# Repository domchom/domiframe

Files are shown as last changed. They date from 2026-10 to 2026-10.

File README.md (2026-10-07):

# DomiFrame

Battery-powered color e-paper photo frames. Friends send pictures from a link on their phone; the frame picks them up on its next check-in.

- **Frame:** one of
  - Seeed XIAO ePaper Display Board **EE04** (XIAO ESP32-S3 Plus) + Seeed **7.3"** E Ink Spectra 6 panel (800×480), or
  - Seeed XIAO ePaper Display Board **EE02** (XIAO ESP32-S3 Plus) + Seeed **13.3"** E Ink Spectra 6 panel (1200×1600)
  - plus a 3.7 V LiPo
- **Server:** Netlify (static site + Functions + Blobs) at `domiframe.art`
- **Upload page:** dithers the photo to the panel's 6 inks in the browser, then **encrypts it there** with the frame's code, so the server only stores ciphertext

```
Friend's phone ──POST image──▶ domiframe.art ──▶ Netlify Blobs (picture queue per frame)
                                                      │
Frame (wakes on schedule or KEY1) ──GET + ETag────────┘
   304 unchanged → sleep     200 new picture → redraw (~20 s) → sleep
   Every reply says how long to sleep (X-Sleep-Minutes)
```

Each frame keeps up to 200 pictures, optionally sorted into folders; the frame cycles through one folder or all of them, in order or shuffled. New ones go up at the next check-in; any picture can be put up next on demand, or set to show only on a day (a birthday, every year); otherwise the frame rotates through them on a schedule (every hour, 3/6/12 hours, day, 3 days, week, or only when something new arrives). The server also decides when the frame wakes next: the check-in interval, quiet hours overnight, and fewer check-ins when the battery is low. When a check-in doesn't get through (no Wi-Fi, server down), the frame retries at its usual interval (`X-Retry-Minutes`), waiting twice as long after each failure in a row, up to 12 hours. A frame on USB power (firmware 0.9.8 tells the server with `X-Power: usb`) can **stay awake when plugged in**: with that setting on, it doesn't sleep, keeps Wi-Fi up and checks in every 5 minutes (`X-Awake-Seconds`), so new pictures go up within 5 minutes; quiet hours still put it to sleep, and unplugged it sleeps as usual. It only knows it's plugged in when there's no battery reading, i.e. no battery connected. When the battery is all but empty, the frame stops checking in and leaves its picture up (e-paper needs no power to keep it); it starts again once it's charged. Removed pictures stay in Recently removed for 30 days, so they can be put back. A frame that has never had a picture gets three paintings in a **Default** folder the first time its page is opened with its code (Hokusai's *Under the Wave off Kanagawa*, Van Gogh's *The Bedroom* and Seurat's *A Sunday on La Grande Jatte*, public domain from the Art Institute of Chicago, in `web/defaults/`), so a new or newly gifted frame isn't blank. The server can't add them itself (only someone with the code can seal pictures), so the first browser to ask claims them (`POST /api/frames/:id/defaults`); it happens once per frame code, and never to a frame that has had pictures. All of this is set per frame on the upload or admin page, with no reflashing.

## Several frames, and alerts

- **Also send to:** anyone with more than one frame opened on their device can send the same photos to several at once, from the upload page or the iPhone app. Each frame gets its own copy, made for its screen and orientation with the same crop, look and text, and sealed with its own code.
- **Alerts (iPhone app):** the app can tell you when a frame is late or its battery is low. The app registers its push token per frame (`/api/frames/:id/alerts`); every half hour `netlify/functions/send-alerts.mjs` checks those frames (`netlify/lib/alerts.mjs`) and sends through APNs (`netlify/lib/push.mjs`). Each problem is told once until it's over, and only between 8:00 and 21:00 where the frame hangs. A new frame code stops all of a frame's alerts. Locally, `POST /__dev/alerts` runs the check now and prints alerts if no APNs key is set.

## Repo layout

| Path | What it is |
|---|---|
| `web/` | Static site: home page (about + My frame), friend upload page, dithering (`dither.js`), encryption (`seal.js`), virtual frame (`sim.html`) |
| `netlify/functions/` | API endpoints |
| `netlify/edge-functions/invite-preview.js` | Invite links (`/f/<id>`) as a rich link in Messages etc.: the frame's ID in the preview tags, and the invite card `web/og-invite.png` (the home page's photo, in a frame). The code, after the `#`, never reaches the server |
| `netlify/lib/common.mjs` | Shared helpers (stores, key hashing, picture queue storage) |
| `netlify/lib/schedule.mjs` | Which picture to show and when the frame wakes (pure functions) |
| `web/admin.html` | Admin page: create frames, see battery and check-ins, replace keys |
| `firmware/` | PlatformIO project for the EE04 |
| `test/` | `npm test`: dithering, scheduling, full API flow against a local Blobs server |
| `scripts/` | `npm run local`: local server + virtual frame; `make-icons.py` redraws the favicons and link-preview images |
| `.github/workflows/ci.yml` | Runs the tests and compiles the firmware on every push |

## API

| Route | Auth | Purpose |
|---|---|---|
| `POST /api/admin/frames` `{id, name, panel?}` | admin | Create a frame; returns `deviceKey` (shown once). No frame code: the frame makes that |
| `GET /api/admin/frames` | admin | List frames: check-ins, battery, settings, picture counts (nothing uploaded) |
| `DELETE /api/admin/frames/:id` | admin | Delete a frame and its pictures |
| `POST /api/admin/frames/:id/keys` `{key: "device"}` | admin | Replace the device key (old one stops working), shown once |
| `PUT /api/admin/frames/:id/settings` | admin | Settings other than the folder, e.g. `orientation` |
| `POST /api/frames/:id/code` `{hash}` | `X-Device-Key` | The frame registers a new code (SHA-256 of the token derived from it); puts the frame's pictures aside for 30 days, or brings them back if it's the code from before |
| `GET /api/frames/:id/image` | `X-Device-Key` | Frame download, sealed (`ETag` / `304`, `204` if empty), always with `X-Sleep-Minutes`, `X-Retry-Minutes`, `X-Orientation`, `X-Flip` and `X-Local-Time`, and `X-Fw-Update` etc. when newer firmware is out. `X-Next: 1` moves to the next picture now (KEY2); `X-Status: 1` only checks in (`204` with `X-Frame-Name` and `X-Pictures`) |
| `POST /api/frames/:id/image` | upload key | Add a picture: packed image, preview PNG, and optionally `thumb` JPEG, original JPEG, `edits`, `from`, `album`, `queue` |
| `GET /api/frames/:id/info` | upload key | Name, check-ins, battery, settings, picture queue |
| `GET /api/frames/:id/preview` | upload key | PNG of the picture on the frame now |
| `PUT /api/frames/:id/settings` | upload key | `rotateHours`, `checkMinutes`, `album`, `order`, `quiet`, `quietStart`, `quietEnd`, `tz`, `orientation`, `flip` (hung upside down) |
| `GET /api/frames/:id/pictures/:pic` | upload key | One picture's PNG preview |
| `GET /api/frames/:id/pictures/:pic/thumb` | upload key | Small JPEG for the picture grid (the PNG preview for older pictures) |
| `GET /api/frames/:id/pictures/:pic/original` | upload key | The photo as uploaded (JPEG), for editing again |
| `PUT /api/frames/:id/pictures/:pic` | upload key | Replace with an edited version (keeps place and folder) |
| `POST /api/frames/:id/pictures/:pic/show` | upload key | Put it up at the next check-in |
| `DELETE /api/frames/:id/pictures/:pic` | upload key | Remove one picture (to the trash) |
| `DELETE /api/frames/:id/pictures` `{ids}\|{album}\|{all: true}` | upload key | Remove several (to the trash); returns their `ids` |
| `PATCH /api/frames/:id/pictures` `{ids, album}` | upload key | Move to a folder (`album: null` = none) |
| `PATCH /api/frames/:id/pictures` `{ids, day}` | upload key | Show only on a day: `"MM-DD"` every year, `"YYYY-MM-DD"` once, `null` = any day |
| `POST /api/frames/:id/restore` `{ids}` | upload key | Put pictures back from the trash |
| `DELETE /api/frames/:id/trash` `{ids}\|{all: true}` | upload key | Delete pictures in the trash for good (otherwise after 30 days) |
| `POST /api/frames/:id/defaults` | upload key | `{claimed}`: true for the one browser that should add the default pictures (a frame that has never had any, once per code) |
| `POST /api/frames/:id/albums` `{name}` | upload key | New folder |
| `PUT`/`DELETE /api/frames/:id/alerts` `{apns, sandbox?, tz?}` | upload key | Start/stop alerts to the iPhone app when the frame is late or its battery is low |
| `PATCH`/`DELETE /api/frames/:id/albums/:album` | upload key | Rename / delete (`?pictures=keep\|delete`) |

"admin" means `Authorization: Bearer <ADMIN_TOKEN>`; "upload key" means `Authorization: Bearer <token derived from the frame code>` (below). The admin token does **not** open any frame's pictures.

Image format: 4 bits per pixel, two pixels per byte (high nibble = left), rows in the panel's own layout: 7.3" = 800×480 (192,000 bytes), 13.3" = 1200×1600 (960,000 bytes). Pictures made for the frame's orientation are turned 90° clockwise when it hangs the other way from the panel's rows (`toPanelOrder` in `web/dither.js`). A frame hung upside down (`flip`) gets the same pictures and turns everything it draws 180° itself (firmware 0.9.7 and later); the picture's ETag changes with `flip`, so the frame draws it again the other way up. Each frame has a `panel` setting (`"7.3"` or `"13.3"`); it is chosen when the frame is created on the admin page; the firmware reports its own on every check-in (`X-Panel`), while the virtual frame only does when its size is changed and otherwise takes the size from the reply (`X-Panel`, like `X-Orientation`). Pictures made for another screen size are never sent.
Palette indices: `0 black, 1 white, 2 yellow, 3 red, 4 blue, 5 green` (shared by `web/dither.js` and `firmware/src/main.cpp`).

Picture files never change (editing a picture gives it a new id), so they're served with `Cache-Control: immutable` and browsers only download each one once. Changes to a frame's picture queue are conditional writes (`onlyIfMatch`), retried on conflict, so a frame checking in during an upload can't lose a picture.

## Privacy: pictures are end-to-end encrypted

Nobody who runs the server (including you, the developer) can see what people send. Each frame makes its own **frame code** like `K7PX-92QD-M4TR-8WZN` (16 characters of Crockford base32, 80 random bits from the ESP32's hardware RNG) and shows it on its screen. The code never goes to the server:

- From the code and frame ID, `web/seal.js` derives two unrelated keys with HKDF-SHA256: an **access token** (sent as the bearer token; the server stores only its SHA-256) and an **AES-256-GCM key**.
- The upload page seals everything before it leaves the browser: the frame picture, preview, thumbnail, original photo, edit settings, sender name and folder names. The server stores and serves ciphertext (`application/octet-stream`).
- The frame derives the same key (`frameKey` in `firmware/src/main.cpp`, mbedtls) and opens the picture before drawing it. The virtual frame does the same with WebCrypto.
- The admin page creates frames and device keys, and shows battery, check-ins and picture counts. It never gets a frame code and can't open, replace or delete anyone's pictures.

The frame's code screen also has a QR code of `https://domiframe.art/f/<id>#k=<code>` (drawn with ESP-IDF's built-in QR encoder), so a phone can open the frame straight away. Codes can also be typed: the home page's **My frame** tab takes a frame ID and code (or a pasted link) and remembers frames opened on that device. Codes are forgiving about case, spaces, dashes and O/I/L (`web/code.js`). In links the code travels in the `#fragment`, which browsers never send, and the upload page removes it from the address bar once saved.

**New code:** on the frame's Wi-Fi setup page (hold KEY3 and press reset), open *Frame details* and tick *Make a new frame code*. The old code stops working. The frame's pictures and folders were sealed with the old code, so they're put away: still sealed, and back only if the frame goes back to that code (type it into the setup page's *Frame code* field) within 30 days, after which they're deleted. The same field gets a wiped frame back to its code and pictures. Changing the frame ID also makes a new code. If you set a frame up before gifting it, the new owner can do this so only they have the code, at the cost of the pictures sent before (the new code starts with the default paintings). **Show the code again:** hold KEY1 while pressing reset.

**What this protects against:** anyone reading the stored data, the database, logs, or the admin page. **What it can't:** the server also serves the web pages, so whoever controls the site could in principle ship changed JavaScript that reads codes as they're typed. The CSP (below) stops pages loading code from anywhere else, but the site's own code has to be trusted. What the server does see: frame names, when pictures were uploaded, how many there are, and settings.

## Other protections

- **Security headers** on every page and API reply (`netlify.toml`, also sent by `npm run local`): a strict Content-Security-Policy (only this site's own scripts, no inline code, requests only to this site, no framing), HSTS, `X-Frame-Options: DENY`, `Cross-Origin-Opener-Policy`, `Cross-Origin-Resource-Policy`, `Permissions-Policy`, `nosniff`, `no-referrer`. No third-party scripts: the virtual frame's QR library is a copy in `web/vendor/`.
- **Keys:** device keys and access tokens are stored only as SHA-256 hashes and compared in constant time. The admin token is kept in the browser tab's `sessionStorage` (gone when the tab closes), and it works only on `/api/admin/*`.
- **Wi-Fi setup:** the `DomiFrame-Setup` Wi-Fi has a new random password each time, shown on the frame's screen (and in its join QR code), so nobody nearby can join it without seeing the frame. The setup page (`firmware/src/portal.cpp`, served by the frame itself) never shows the saved device key, frame code or Wi-Fi password back, and has no firmware upload: updates only come signed, over Wi-Fi.
- **Frame to server:** TLS is checked against Mozilla's root CAs (below). Sealed pictures that don't open with the frame's key (tampered with, or sealed with an old code) are never drawn.

## Deploy (Netlify)

1. New site from this GitHub repo. Build settings come from `netlify.toml` (publish `web`, functions `netlify/functions`). Pushes that only change firmware, tests or docs skip the deploy (`ignore` in `netlify.toml`), which saves credits on the Free plan.
2. **Site configuration → Environment variables:** add `ADMIN_TOKEN` (a long random string, e.g. `openssl rand -base64 32`). Optionally `PUBLIC_URL=https://domiframe.art`.
   For the iPhone app's alerts, also add an APNs key (Apple Developer → Certificates, IDs & Profiles → Keys, with Apple Push Notifications service): `APNS_KEY` (the `.p8` file's contents), `APNS_KEY_ID`, `APNS_TEAM_ID`, and `APNS_TOPIC` if the app's bundle ID isn't `art.domiframe.app`. Without them, nothing is sent.
3. **Domain management:** add `domiframe.art` and follow Netlify's DNS instructions at your registrar.

## Add a frame

Open `https://domiframe.art/admin.html`, sign in with `ADMIN_TOKEN`, and use **Add a frame**. It shows the device key once, with a link to try it as a **virtual frame** right away. Once the frame (real or virtual) is set up, it makes its frame code and shows it on its screen: give that code and the frame ID to the owner. **New device key** replaces a leaked key.

Or with curl:

```bash
curl -X POST https://domiframe.art/api/admin/frames \
  -H "Authorization: Bearer $ADMIN_TOKEN" -H "Content-Type: application/json" \
  -d '{"id":"emma","name":"Emma'\''s frame"}'
```

Save the response and enter `id` + `deviceKey` on the frame (below). The frame then shows its code.

## Flash and set up a frame

1. 7.3": set the EE04 jumper to **50-pin** for the Seeed 7.3" panel. 13.3": connect the panel to the EE02's 60-pin connector.
2. Flash the build for your screen (PlatformIO), with the board on USB-C:
   - 7.3" on EE04: `cd firmware && pio run -e ee04 -t upload`
   - 13.3" on EE02: `cd firmware && pio run -e ee02-13in3 -t upload`
3. On first boot the screen says **Set up Wi-Fi**, with a QR code. Scan it with a phone's camera to join the frame's own `DomiFrame-Setup` Wi-Fi (or join it by hand with the password on the screen), and a setup page opens: pick the home network, type its password, choose how the frame hangs, fill in **Frame ID** and **Device key**, and press **Connect**. The page says whether it worked; a wrong password keeps it open to try again. The orientation can also be changed later on the upload or admin page.
4. The frame connects, makes its **frame code** and shows it with the frame ID and a **QR code**. Scan the QR code to open the frame's page with the code filled in, or enter the ID and code under **My frame** on domiframe.art.
5. When the frame is switched on (or reset, or KEY1 is pressed) and can't reach its Wi-Fi, because it has moved or been given away, it opens setup by itself. Only the Wi-Fi is asked for: the frame's details are under *Frame details*, and its pictures stay. On a timer wake it just keeps its picture and tries again later. To open setup anyway (a new frame code, say), hold **KEY3** while pressing reset. Hold **KEY1** while pressing reset to show the code again (no Wi-Fi needed).
6. **KEY1** wakes the frame to check for a new picture immediately. **KEY2** wakes it and puts up the next picture (`X-Next: 1`; it then stays a whole turn). Hold **KEY2** while pressing reset for the status screen: battery, Wi-Fi and signal, whether the server answers (a check-in with `X-Status: 1`, which leaves the picture as it is) and the last check-in that got through, in the frame's time zone (`X-Local-Time`).

You can do step 3 yourself with your own Wi-Fi before gifting it, and open its page so it gets the default paintings (and send any pictures you'd like waiting). Switch it off before sending it: when your friend switches it on at home, it can't find your Wi-Fi, opens setup, and they only pick theirs. To keep their pictures private from you, they can open *Frame details* there and tick *Make a new frame code*, though the pictures sent before are put away with the old code. The support page has the same steps (`web/support.html#gift`).

## Firmware updates over Wi-Fi

Frames update themselves: when a newer release is out for their build, the check-in reply offers it (`X-Fw-Update`, `X-Fw-Url`, `X-Fw-Size`, `X-Fw-Sig`), and the frame downloads it into the spare app slot, checks it, and restarts into it. The picture stays on the screen, and the frame keeps its Wi-Fi, settings and frame code, so its pictures stay too. It only installs firmware **signed with your key** (ECDSA P-256, checked against the public key built into it), only a newer version of the same build, and only with enough battery (`MIN_UPDATE_MV`). The new firmware only counts as good once it has reached the server; until then the bootloader can roll it back, where it supports that. Three failed tries at one version and the frame waits for a newer one.

1. Once: `cd firmware && python3 tools/release.py keygen`. This makes the signing key at `~/.domiframe/firmware-signing-key.pem` (outside the repo: back it up, never commit it) and writes its public half into `include/fw_key.h`. Commit that file, and flash each frame **once over USB** so it has the key. Until `fw_key.h` holds a key, frames don't ask for updates.
2. Each release: raise `FW_VERSION` in `include/config.h`, then `python3 tools/release.py publish`. It builds both screens, signs them, puts them in `web/firmware/` and lists them in `netlify/lib/firmware-releases.mjs`.
3. Commit and push. Once Netlify deploys, each frame updates at its next check-in.

Lose the key and frames can't take updates over Wi-Fi any more: make a new one with `keygen`, and flash every frame over USB again.

## Local development

```bash
npm install
npm test        # dithering + API flow
npm run local   # whole system locally, with a virtual frame (no hardware, no Netlify account)
npx netlify dev # site + functions locally (needs netlify-cli)
```

### Testing without hardware

**Virtual frame** (`/sim.html`, also live at `https://domiframe.art/sim.html`): a browser stand-in for the frame that works against the real site too. Create a frame on the admin page and press **Open as a virtual frame** (or enter the frame ID and device key on the page). Like the firmware, it makes its own frame code, registers it, shows it on its screen, sends the device key, battery and `If-None-Match`, opens the sealed picture with its code, and decodes the packed 4bpp image with the same palette. **Open this frame's page** opens the upload page with the code. Press **KEY1** to check in, or turn on auto wake. The device key and code are kept in that browser's storage.

`npm run local` starts the site and API on `http://localhost:8888` with a local Blobs store in `.local/`. It creates a `demo` frame and prints a link to the virtual frame for it. Use the battery slider to test the upload page's battery display.

To start over, delete `.local/`. The admin page is at `/admin.html` with the token `local-admin`.

To test schedules, the virtual frame can follow the server's `X-Sleep-Minutes` in real time or sped up, or skip ahead an hour, day or week. The local server moves its clock to match (`/__dev/clock`, local only), so you can watch hourly or weekly rotation and quiet hours in seconds.

## Status / to verify on real hardware

- Firmware **compiles** (CI builds both screens on every push) but has **not run on hardware yet**. 7.3": pins come from Seeed's `Seeed_GFX` EE04 setup and the EE04 wiki; the display uses GxEPD2's `GxEPD2_730c_GDEP073E01` driver, which targets the same ED2208 controller as Seeed's 7.3" Spectra 6 panel. 13.3": uses Seeed's own `Seeed_GFX` (`BOARD_SCREEN_COMBO=510`, T133A01 driver), pinned to a known commit.
- EE02 buttons and battery pins aren't published; the 13.3" build assumes they match the EE04 (its display pins do). Check against the EE02 schematic.
- On a frame hung the other way from its panel's rows (a portrait 7.3", a landscape 13.3"), check that pictures and status messages are the right way up; if not, flip `rotateCW` in `web/dither.js` and the rotation in `showMessage()`.
- TLS: the frame checks the server's certificate against Mozilla's root CAs, embedded as `firmware/data/cert/x509_crt_bundle.bin` (`VERIFY_TLS` in `config.h`), so it keeps working whichever CA issues the certificate. Unlike a browser, the ESP32 only looks up the issuer of the *last* certificate the server sends, so after pointing domiframe.art at Netlify, check it: `python3 firmware/tools/make_ca_bundle.py --check domiframe.art` (CI also runs this weekly). If it names a missing root, add it to `firmware/tools/extra_roots.pem`, rebuild the bundle and reflash. Rebuild it every year or so anyway: `python3 firmware/tools/make_ca_bundle.py`.
- Wi-Fi: the frame remembers the access point and channel in RTC memory across deep sleep and reconnects without scanning, falling back to a normal connect if that fails within 5 s.
- How each frame hangs (landscape or portrait) is a frame setting. Pictures for a portrait frame are packed turned 90° clockwise onto the panel; if they come out upside down on a real portrait-hung frame, flip the rotation in `web/dither.js` (`rotatePortraitToPanel`).
- Palette RGB values in `web/dither.js` are approximations of the real inks; tune them after comparing the preview with the panel.
- Battery reading uses Seeed's `raw / 4096 × 7.16` formula; check against a multimeter.

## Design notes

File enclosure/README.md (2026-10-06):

# Frame case

A 3D-printable case for the 7.3" panel, the Seeed XIAO ePaper Display Board and a LiPo battery. The screen glass is 169 × 111 mm, with a 160 × 96 mm image area. The battery space fits an 80 × 55 × 9 mm pack, so there's room for the larger battery you plan to use later.

The size starts from hextheboy's [7.3 inch E-ink Paper Frame](https://makerworld.com/en/models/1710103-7-3-inch-e-ink-paper-frame) on MakerWorld (191.2 × 132.2 × 16 mm). This version is 196.2 × 132.2 × 17 mm:

- **1 mm deeper**, so there's 7.4 mm of free space above the board for the battery connector. The model refuses to render if that drops below `board_clearance` (6 mm) plus 0.5 mm.
- **5 mm wider**, so the bezel is 18.6 mm on all four sides. The screen's image area isn't centred on its glass, so the glass sits 4 mm low in the frame to centre the window. Set `equal_bezels = false` to go back to the reference width with a wider bottom bezel.

Everything fits inside that depth, so the back is a flat plate with no lid sticking out. The board sits against the top wall, with its buttons, slide switch and USB-C facing up. The top wall has an opening for the USB-C plug and a round hole over each button. A small printed cap goes through each hole and presses onto the switch's plunger. The slide switch has a slot, and its cap has a wider tab outside so it's easier to push.

| File | Print orientation |
| --- | --- |
| `stl/frame.stl` | front face down |
| `stl/back.stl` | outside face down |
| `stl/buttons.stl` | four button caps and the switch cap, outer face down |
| `stl/fit_test.stl` | fit test caps, see below |
| `stl/rail.stl` | landscape hanging rail and two spacers, back face down |
| `stl/stand.stl` | two stand feet, flat on their side |

The source is `domiframe_case.scad`. All the dimensions are parameters at the top of the file.

## Check these before printing

Most of these numbers came from a photo, so measure your parts first:

- **`edge_to_hole`** (now 2.5 mm): the distance from the button edge of the board to the centres of the nearest mounting holes. The standoffs set where the board sits, so if this number is wrong, the buttons won't line up with the slot.
- **`board_len` / `board_wid`** (now 80 × 41.2 mm): the outline of the board.
- **`usb_x`** (now −25): where the USB-C sits along the top wall. The buttons are placed from it: the first is `btn_first` (16.87 mm) away, then every `btn_pitch` (9.16 mm). If they all end up on the wrong end, flip the sign of `usb_x` and set `btn_dir = -1`.
- **`usb_above_pcb`** (3.0 mm): how far the centre of the USB-C port sits above the top of the PCB. The opening is centred on this height. It's 12.5 × 7 mm (`usb_hole_w`, `usb_hole_h`) so the plug's overmold can go partway into the wall. If your cable's overmold is bigger, make the opening bigger.
- **`usb_overhang`** (0): if the USB-C socket sticks out past the board edge by more than 0.3 mm, set this to how far. It cuts a groove up the inside of the wall so the socket can slide in when the back plate goes in.
- **`btn_from_back`** (8.15 mm, measured): how far the centre of each plunger sits from the back face of the frame. The holes and caps are centred on this height.
- **`sw_window`** (3.84 mm, measured): the opening in the switch body. The knob slides 3.84 − 1.55 = 2.29 mm in it. `sw_on_from_btn` (10.75 mm, measured) places it in the ON position, counted from the last button, and OFF is `sw_travel` back toward the buttons. The slot is also 1.5 mm taller than it needs to be (`sw_z_play`, 0.75 mm on each side), because the knob's distance from the back (`sw_from_back`, 8.15 mm) doesn't seem to be exactly the same each time.
- **`sw_post_len`** (1.5 mm): how far the knob sticks out of the switch body. The cap goes `sw_grip` (1 mm) onto it.
- **`btn_tip`** (0): where the tip of each plunger sits relative to the board edge. It's negative if the tip stops short of the edge. Each cap's sleeve reaches in to the plunger, so this sets how long the caps are.
- **`btn_post_len`** (1.5 mm): how far each plunger sticks out of the switch body. Each cap goes `btn_grip` (1 mm) onto the plunger and no further, because its socket is closed at the end. The model refuses to render unless `btn_travel` (0.3 mm) plus 0.1 mm is left between the cap and the switch body, so the cap doesn't hold the button down.
- **`aa_top`** (5 mm): the gap between the top edge of the glass and the top of the image area. The bottom border, on the FPC side, works out to 10 mm, and each side to 4.5 mm.

The quickest check is to print only a strip of the top wall and hold your board against it.

### Button caps

The plungers taper from 2.35 mm at the base to 2.3 mm at the tip. The socket in each cap is drawn at 2.3 mm (`btn_bore`). Small printed holes usually come out about 0.1 mm undersize, and that gives the press fit. Print `fit_test.stl` first. It has four button caps with sockets of 2.2, 2.3, 2.4 and 2.5 mm, marked with 1 to 4 dots on the outer face. Push each one onto a plunger, and set `btn_bore` to the socket size of the one that holds firmly without splitting.

The switch knob is a 1.55 mm square, and its cap's socket is drawn at that size (`sw_socket`). The fit test also has three switch caps with sockets of 1.45, 1.55 and 1.65 mm, marked with 1 to 3 dots. Set `sw_socket` the same way.

## Rendering

Export all the parts to `stl/`:

```bash
./export.sh
```

Name parts to export only those, for example `./export.sh back buttons`.

In the OpenSCAD app, open **Window → Customizer** and pick a part from the **Part** dropdown. Press F6 to render it and F7 to save it as an STL. `assembly` shows everything together with placeholder blocks for the panel, board and battery. `section` cuts the assembly in half at X = 0 so you can see the inside. The measurements are grouped into tabs in the same panel.

## Assembly

1. Put the panel face-down in the frame, with its FPC tail at the bottom in the notch.
2. Screw the board onto the back plate's standoffs with 4 × M2 × 4 screws, components facing out. The button edge goes toward the top.
3. Put the battery in its fence with double-sided foam tape, leads toward the board. The fence is sized for an 80 × 55 × 9 mm pack, so tape a smaller battery into the corner nearest the board. The fence sits left of centre, seen from the back, which leaves the right half free for the ribbon. If the board's ribbon connector is on the other side, move it with `bat_x`. Stick the antenna flat on the plate, away from the battery.
4. Connect the extension ribbon from the board to the panel tail, then plug in the battery.
5. Lower the plate into the back of the frame, top edge first, so the buttons and USB-C line up with their holes. Fix it with 6 countersunk M2 self-tapping screws. The holes in the frame are 2.1 mm across and 11 mm deep (`frame_pilot`, `frame_pilot_depth`), so screws up to M2 × 12 fit.
6. Push a cap into each button hole from outside until it stops on the plunger. Push the switch cap through its slot onto the knob in the same way. Each cap stands 1 mm proud of the wall. To take the back plate out again, pull the caps first.

The back plate says what each button does, under the button: **RESET**, **1 CHECK** (check for pictures now; hold it while pressing reset to show the frame code), **2 NEXT** (the next picture now; hold it while pressing reset for the frame's status) and **3 SETUP** (hold it while pressing reset to open Wi-Fi setup).

The pads in the corners and on the sides stop 0.3 mm short of the panel. A thin strip of foam on each pad keeps the panel from rattling.

## Hanging and standing

Both work in portrait or landscape.

**On the wall** with a sawtooth bracket (two screws, 32.22 mm apart, `hang_pitch`):

- **Portrait:** there are two holes through the back plate on each long side, into the solid part of the frame. Screw the bracket to whichever side you want at the top. It sits flush with the back.
- **Landscape:** the board fills the top of the case, so the bracket can't screw in there. Instead it goes on `rail.stl`, which runs across the top. Swap the two top corner screws for M2 × 12 so they go through the rail, and screw the bracket into the two holes in the middle of the rail. The two small spacers go on the bottom corner screws, also M2 × 12, so the frame hangs straight. The rail and spacers add 6 mm behind the frame (`rail_t`). The bracket's screws go up to 5 mm into the rail. If yours are longer than the bracket's thickness plus 5 mm, they'll bottom out.

**On a table**, slide the two feet in `stand.stl` onto the bottom edge, one near each end. They hold the frame leaning back 15° (`stand_lean`). They grip any edge, so the same feet work in portrait and landscape. The slot is 0.3 mm wider than the frame (`stand_fit`). Lower this if the feet are loose.

Open `hanging` or `standing` in the Customizer to see either setup.

## Print notes

- 0.2 mm layers, 3 walls, 15% infill. PLA or PETG.
- The top of the USB-C opening is a short bridge, and the button holes are small enough to print round.
- Print the feet flat on their side as exported, so the slot needs no supports.
- Print the caps at 0.12 mm layers or finer. Their sleeve walls are only 0.5 mm.
- No supports needed on any part.

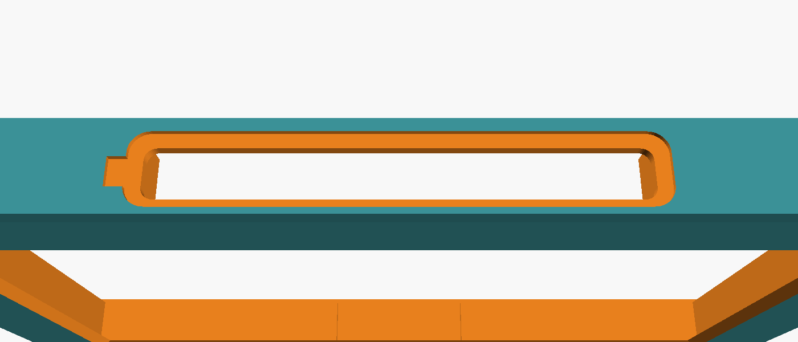
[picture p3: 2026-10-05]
enclosure/slot-preview.png

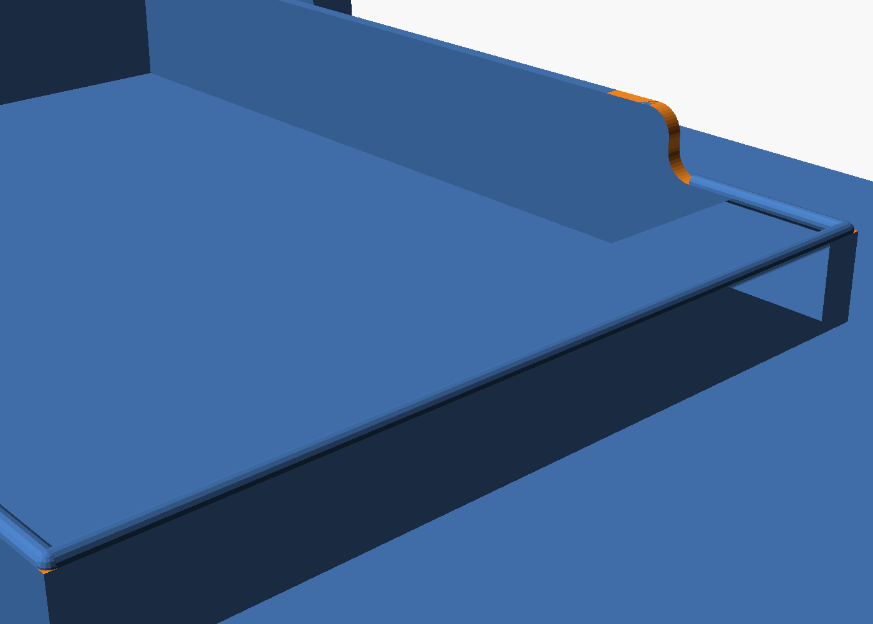
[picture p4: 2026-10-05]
enclosure/back-detail.png

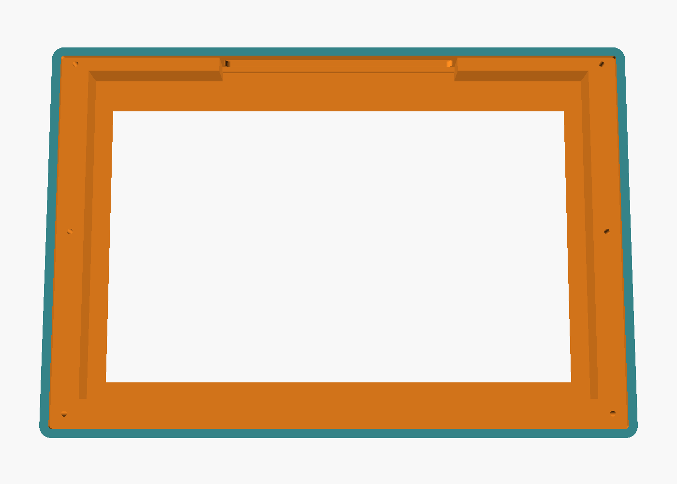
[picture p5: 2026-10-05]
enclosure/frame-back.png

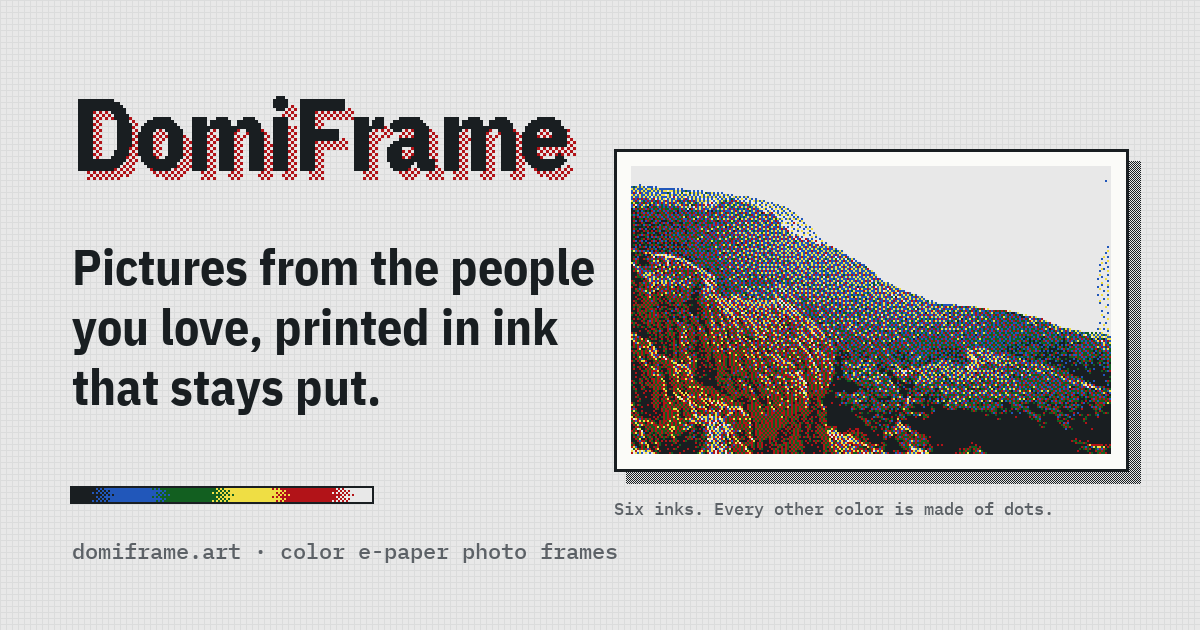
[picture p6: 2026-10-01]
web/og.png

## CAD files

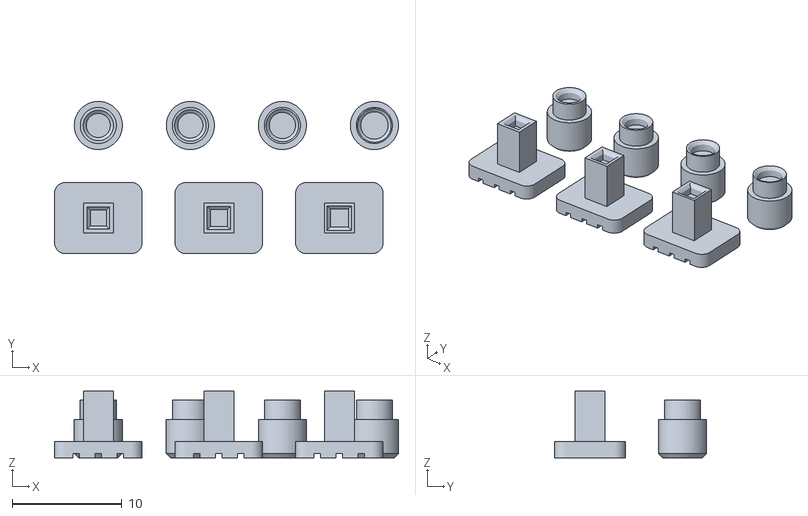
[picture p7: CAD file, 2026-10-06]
enclosure/stl/fit_test.stl
31.4 x 13.9 x 6.10

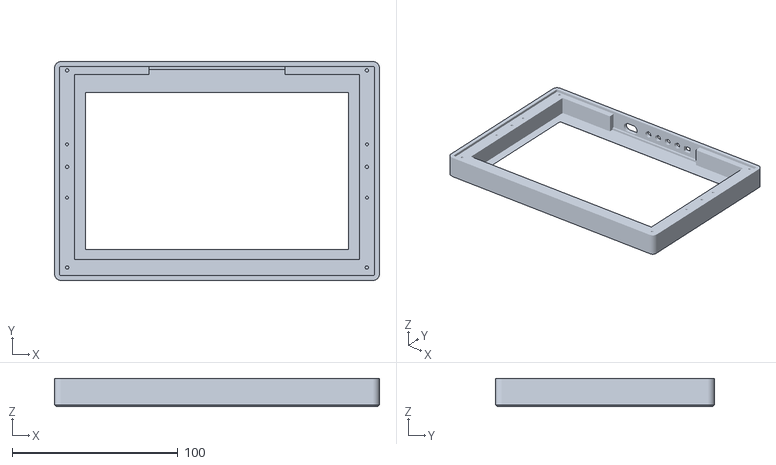
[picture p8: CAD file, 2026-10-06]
enclosure/stl/frame.stl
196.2 x 132.2 x 17.0

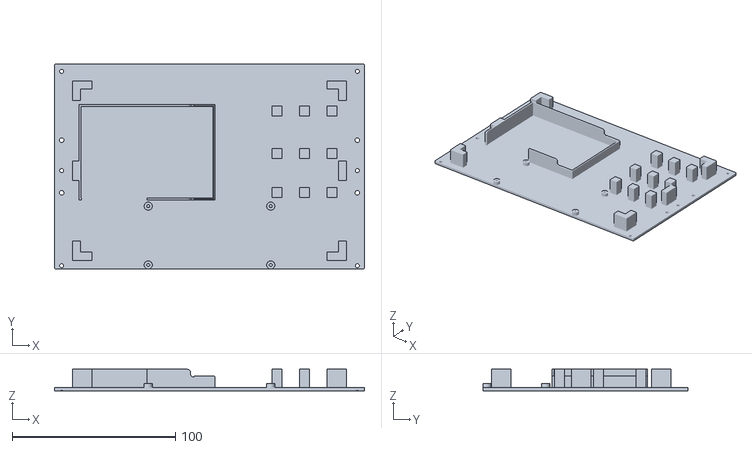
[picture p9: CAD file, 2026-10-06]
enclosure/stl/back.stl
189.8 x 125.8 x 13.2

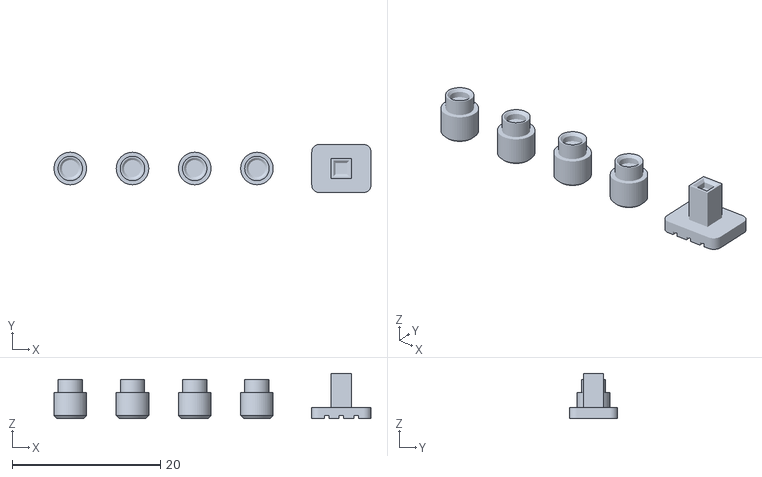
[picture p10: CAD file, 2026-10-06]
enclosure/stl/buttons.stl
42.8 x 6.50 x 6.10

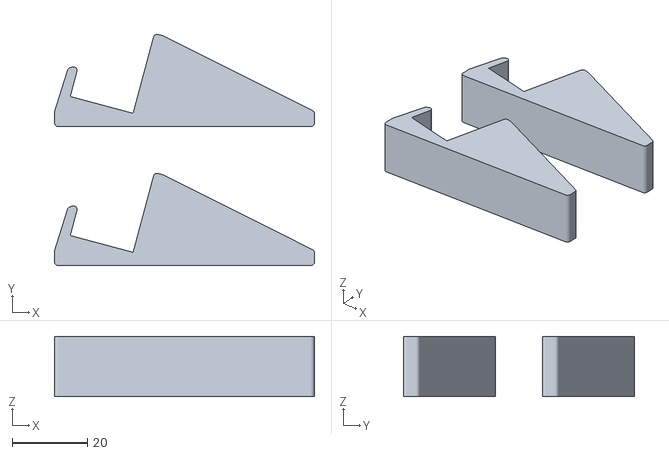
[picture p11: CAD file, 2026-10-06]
enclosure/stl/stand.stl
69.2 x 61.6 x 16.0

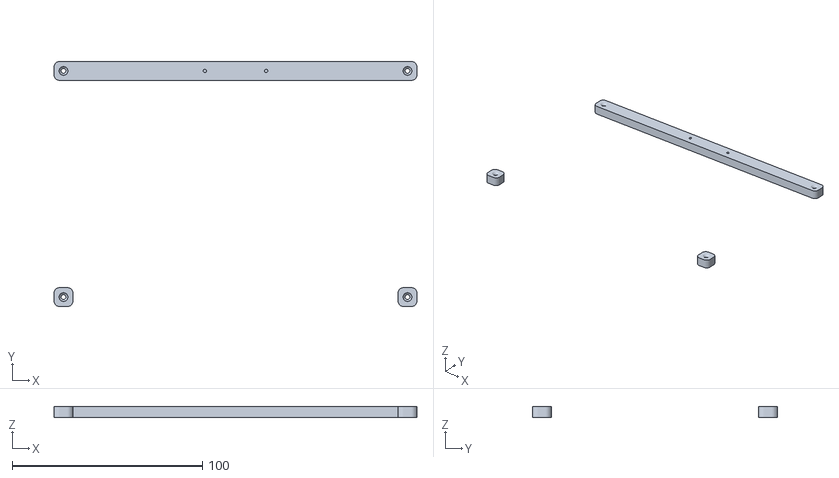
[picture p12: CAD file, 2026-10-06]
enclosure/stl/rail.stl
191.0 x 129.0 x 6.00

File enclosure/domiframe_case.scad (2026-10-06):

// domiframe case: frame for a 7.3" e-paper panel driven by a
// Seeed XIAO ePaper Display Board, with a 603449 LiPo inside.
//
// Outer size follows hextheboy's "7.3 inch E-ink Paper Frame" on MakerWorld
// (191.2 x 132.2 x 16 mm); here it is 1 mm deeper and, with equal_bezels,
// 5 mm wider. The back is redone for the Seeed board: it sits
// against the top wall with its buttons, slide switch and USB-C facing up.
// The USB-C gets its own opening, and each button gets a hole with a
// printed cap that presses onto the switch's plunger. The slide switch gets a
// slot and a press-on cap with a bigger tab to push.
//
// Hanging: a sawtooth bracket screws through the back plate into the solid frame
// down either side for portrait, or onto a rail across the top for landscape.
// Standing: two slip-on feet hold any edge, so they work either way round.
//
// Coordinates: X across, Y up (top of the frame is +Y), Z into the frame.
// Z = 0 is the front face. The back plate sits flush at Z = D.
//
// Pick a part from the dropdown in Window > Customizer, render (F6) and
// export (F7). ./export.sh writes every part to stl/ in one go.

/* [Part] */
part = "assembly"; // [assembly, frame, back, buttons, fit_test, rail, stand, section, hanging, standing]

/* [Outside] */
H = 132.2;          // frame height
D = 17;             // frame depth (back plate flush with the back)
R = 4;              // corner radius
front_chamfer = 1;

/* [Panel] */
panel_w = 169;      // glass outline
panel_h = 111;
panel_t = 1.2;
panel_clr = 0.4;    // per side
pocket_extra_w = 2; // extra width on the panel pocket, split across both sides
aa_w = 160;         // active area
aa_h = 96;
aa_top = 5;         // glass edge to active area on the side away from the FPC; the FPC side is 10
fpc_top = true;     // FPC tail (the panel's wide border) at the top, by the board and buttons
win_overlap = 0.5;  // bezel covers this much of the active area per side
lip = 2;            // front bezel thickness
panel_pocket = panel_t + 0.3;

// Centre the window and widen the frame so the bezel is the same on all four
// sides. Off: reference width, panel centred, wider bottom bezel.
equal_bezels = true;
W = equal_bezels ? H - (aa_h - 2 * win_overlap) + (aa_w - 2 * win_overlap) : 191.2;

fpc_w = 0;          // width of the FPC notch; 0 = as wide as the board pocket
fpc_notch = 3;

/* [Driver board] */
board_len = 80;          // along the button edge
board_wid = 41.2;
pcb_t = 1.6;
hole_dx = 75;            // mounting holes, centre to centre
hole_dy = 36;
edge_to_hole = 2.5;      // button edge -> nearest hole row (measure yours)
standoff_h = 2.5;
board_clearance = 6;     // free space above the board's top face (battery connector)
standoff_d = 5;
screw_pilot = 1.9;       // M2 self-tapping into the board standoffs
frame_pilot = 2.1;       // M2 self-tapping into the frame, for the back plate screws
frame_pilot_depth = 11;  // from the back rebate toward the front
screw_clear = 2.5;       // M2 clearance through the back plate
screw_head = 4.6;        // countersink diameter for the back plate screws
top_wall = 3;            // wall left between the board and the outside
board_gap = 0.3;         // board edge to that wall

/* [USB-C] */
usb_x = -25;             // USB-C centre, model X (mirror if it lands wrong)
usb_above_pcb = 3.0;     // USB-C centre above the PCB top
usb_hole_w = 12.5;       // opening in the top wall, sized for the plug's overmold,
usb_hole_h = 7;          // which has to go partway into the 3 mm wall
usb_overhang = 0;        // how far the socket sticks out past the board edge; past board_gap
usb_body_w = 9.2;        // this cuts a groove up the inside of the wall so it can slide in
usb_body_h = 3.3;

/* [Buttons] */
// Right-angle switches on the board's top edge. Each gets a hole in the top wall and a cap that
// presses onto its plunger from outside, after the back plate is in.
btn_names = ["RESET", "1 CHECK", "2 NEXT", "3 SETUP"];   // starting from the USB-C end
btn_first = 16.87;       // USB-C centre to the first button
btn_pitch = 9.16;        // button to button
btn_dir = 1;             // which way they run from the USB-C (model X); flip with usb_x
btn_from_back = 8.15;    // plunger centre to the back face of the frame
btn_tip = 0;             // plunger tip past the board edge; negative if it stops short of it
btn_post_len = 1.5;      // plunger length out of the switch body
btn_post_d = 2.3;        // plunger at the tip (2.35 at the base)
btn_bore = 2.3;          // socket in the cap; printed holes come out ~0.1 small, which is the grip
btn_grip = 1.0;          // how far the cap goes onto the plunger; the socket is blind so it stops there
btn_travel = 0.3;        // switch travel, kept clear between the cap and the switch body
btn_wall = 0.5;          // sleeve around the plunger
btn_head_d = 4.4;        // the part in the wall
btn_clr = 0.25;          // per side, head to hole
btn_proud = 1;           // how far the cap stands out of the wall

/* [Slide switch] */
// Past the last button, ON toward the outside. Its 1.55 mm square knob gets a cap with a
// bigger tab, sliding in a slot that is taller than it needs to be because the knob's
// distance from the back isn't quite repeatable.
sw_on_from_btn = 10.75;  // last button to the knob in the ON position
sw_window = 3.84;        // opening in the switch body; the knob slides this less its own width
sw_from_back = 8.15;     // knob centre to the back face of the frame
sw_z_play = 0.75;        // extra slot height on each side, front and back
sw_knob = 1.55;          // square knob
sw_socket = 1.55;        // square socket in the cap; prints a little small, which is the grip
sw_tip = 0;              // knob tip past the board edge; negative if it stops short of it
sw_post_len = 1.5;       // knob length out of the switch body
sw_grip = 1.0;           // how far the cap goes onto the knob; the socket is blind
sw_wall = 0.6;           // stem around the knob
sw_clr = 0.25;           // per side, stem to slot
sw_tab = [8, 6.5, 1.5];  // the part you push: along the wall, front to back, thickness
sw_tab_gap = 0.3;        // tab to wall

// What each button does, engraved into the back plate right under it, reading down from the top edge.
button_labels = true;
label_size = 2.6;
label_depth = 0.6;

/* [Battery] */
// Space is sized for the larger pack planned later (80 x 55 x 9). The current
// 50 x 32 x 6 one sits in a corner of the same fence on foam tape.
bat_l = 80;
bat_w = 55;
bat_t = 9;
bat_x = -38.3;           // centre; fence runs from the left pads to just past X = 0
bat_y = -8.8;            // fence top stops just under the board
fence_t = 1.2;           // fence walls run all the way up to the panel
ribbon_wall_h = 7;       // the fence wall on the ribbon side stops at this height so the ribbon can cross it
ribbon_cut_len = 15;     // length of the lowered part, from the fence's right edge
ribbon_round = 2;        // radius on the step down into the lowered part
lead_gap = true;         // opening for the leads in the board-side wall
lead_gap_side = -1;      // which half it goes in: -1 left, 1 right (model X)

/* [Back plate] */
plate_t = 2;
rim = 3;                 // frame wall around the back plate
plate_clr = 0.2;
retainer_gap = 0.3;      // pads, fence and posts stop this short of the panel (add foam)
pad_t = 5;               // how far the edge pads reach in from the glass edge
pad_len = 12;            // length of each pad leg
ribbon_gap = 35;         // clear channel right of the battery for the ribbon
post_size = 6;           // square posts under the panel on the other side
post_rows = [-34, -8, 16];   // post centres, model Y

/* [Wall hanging] */
// Sawtooth bracket with two screws. Portrait: through the back plate into the solid frame
// down either long side. Landscape: the board is in the way at the top, so the bracket goes
// on a rail held by the two top corner screws, with spacers on the bottom two.
hang_pitch = 32.22;      // bracket holes, centre to centre
hang_pilot = 1.8;        // for the bracket's 2.34 mm screws
hang_pilot_depth = 10;   // into the frame, from the back rebate
hang_clear = 2.8;        // through the back plate
hang_portrait_y = 0;     // centre of the bracket along the side (model Y)
rail_t = 6;              // rail and spacer thickness; adds this much behind the frame
rail_h = 10;

/* [Stand] */
// Two identical feet; slide one onto the bottom edge near each end.
stand_lean = 15;         // degrees back from upright
stand_fit = 0.3;         // slot width over the frame depth
stand_front_h = 7;       // lip over the front bezel (the bezel is 18.6)
stand_back_h = 22;       // support up the back
stand_floor = 3;         // under the edge
stand_wall = 2.5;
stand_len = 65;          // front of the foot to the end of the tail
stand_w = 16;            // along the edge
stand_base = 4;

/* [Hidden] */
$fn = 48;
eps = 0.01;
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

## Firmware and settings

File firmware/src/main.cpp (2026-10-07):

// DomiFrame firmware for Seeed's XIAO ePaper Display Boards:
//   env ee04        EE04 + 7.3" E Ink Spectra 6 (800x480), GxEPD2
//   env ee02-13in3  EE02 + 13.3" E Ink Spectra 6 (1200x1600), Seeed_GFX
//
// Each wake: connect to Wi-Fi -> GET /api/frames/<id>/image (with ETag) ->
// redraw only if the picture changed -> deep sleep for as long as the server says
// (X-Sleep-Minutes), so check-in times, quiet hours and picture rotation are set on the server.
//
// Wi-Fi setup (portal.cpp): on first boot, when someone switches the frame on (or resets it, or
// presses KEY1) and it can't reach its Wi-Fi, or with KEY3 held while resetting, the frame opens
// its own network "DomiFrame-Setup" and shows a QR code to join it (and its password). The phone
// gets one page: pick the Wi-Fi, type its password. The frame ID and device key go in there too
// on first setup, then stay out of the way.
//
// Frame code: the frame makes its own random code (like K7PX-92QD-M4TR-8WZN) and shows it on
// its screen; people type it on the website to send pictures. Pictures are sealed in their
// browser with a key derived from the code (web/seal.js), so the server only ever has
// ciphertext; the frame derives the same key and opens them here. The server only gets the
// SHA-256 of a separate access token derived from the code (POST /api/frames/<id>/code).
// Hold KEY1 while pressing reset to show the code again; the setup portal can make a new one,
// or take back the code the frame had (the server then brings back the pictures sealed with it).
//
// Stay awake: on USB power, with "Stay awake when plugged in" on (Frame settings), the frame
// doesn't sleep. It keeps Wi-Fi up and checks in every 5 minutes (X-Awake-Seconds), so new photos
// go up within 5 minutes of being sent. Unplugged, or in quiet hours, it sleeps as usual.
//
// KEY2: press it and the frame wakes and puts up the next picture (X-Next). Hold it while
// pressing reset for the status screen: Wi-Fi, server, battery and the last check-in.
//
// Updates over Wi-Fi: when newer firmware for this build is out, the check-in reply says so.
// The frame downloads it, checks its signature against FW_SIGNING_KEY (include/fw_key.h) and
// installs it. Settings, Wi-Fi and the frame code are kept, so its pictures stay.

#include <Arduino.h>
#include <WiFi.h>
#include <HTTPClient.h>
#include <WiFiClientSecure.h>
#include <Preferences.h>
#include <SPI.h>
#include <esp_wifi.h>
#include <driver/rtc_io.h>
#include <esp_system.h>
#include <mbedtls/md.h>
#include <mbedtls/gcm.h>
#include <mbedtls/aes.h>
#include <mbedtls/base64.h>
#include <mbedtls/pk.h>
#include <Update.h>
#include <esp_ota_ops.h>
#include <qrcode.h>  // ESP-IDF's QR encoder
#include "config.h"
#include "portal.h"
#include "fw_key.h"
#include "pixel_font.h"  // made by the app repo's scripts/make-pixel-font.py, as web/pixelfont.js

// ---- Screen -----------------------------------------------------------------
// W x H is the panel's own pixel layout, which is the order the server sends pictures in.
// Palette index order must match web/dither.js: black, white, yellow, red, blue, green.

#if defined(DOMIFRAME_PANEL_13IN3)
#include <TFT_eSPI.h>  // Seeed_GFX, configured by BOARD_SCREEN_COMBO=510 in platformio.ini
#define PANEL_ID "13.3"
static const int W = 1200, H = 1600;
static const bool NATIVE_PORTRAIT = true;
static const uint16_t PALETTE[6] = {TFT_BLACK, TFT_WHITE, TFT_YELLOW, TFT_RED, TFT_BLUE, TFT_GREEN};
EPaper epaper;
#else
#include <GxEPD2_7C.h>
#define PANEL_ID "7.3"
static const int W = 800, H = 480;
static const bool NATIVE_PORTRAIT = false;
static const uint16_t PALETTE[6] = {GxEPD_BLACK, GxEPD_WHITE, GxEPD_YELLOW, GxEPD_RED, GxEPD_BLUE, GxEPD_GREEN};
// GDEP073E01 uses the same ED2208 controller as Seeed's 7.3" Spectra 6 panel.
GxEPD2_7C<GxEPD2_730c_GDEP073E01, GxEPD2_730c_GDEP073E01::HEIGHT / 4>
    display(GxEPD2_730c_GDEP073E01(EPD_CS, EPD_DC, EPD_RST, EPD_BUSY));
#endif
#include "plex_fonts.h"  // IBM Plex, as on the website, at this screen's own size (tools/make_fonts.py)

static const size_t IMAGE_BYTES = (size_t)W * H / 2;
// Sealed download: IV (12) || ciphertext || GCM tag (16), see web/seal.js
static const size_t GCM_IV_BYTES = 12, GCM_TAG_BYTES = 16;
static const size_t SEALED_BYTES = GCM_IV_BYTES + IMAGE_BYTES + GCM_TAG_BYTES;

#if VERIFY_TLS
// Mozilla's root certificates (firmware/data/cert, made by tools/make_ca_bundle.py), so the
// frame trusts the server's certificate whichever CA issued it. Hosts switch between CAs,
// so a single pinned root would eventually lock every frame out.
extern const uint8_t CA_BUNDLE[] asm("_binary_data_cert_x509_crt_bundle_bin_start");
#endif

// Kept in RTC memory across deep sleep: the access point we joined last time, so the next wake
// can skip the Wi-Fi scan and connect straight away (the radio is the biggest battery drain).
RTC_DATA_ATTR uint8_t rtcBssid[6];
RTC_DATA_ATTR int32_t rtcChannel = 0;
// Failed tries at installing an update (a bad download, a bad signature), so a broken release
// doesn't drain the battery retrying at every check-in. Starts over for a newer version.
RTC_DATA_ATTR uint8_t rtcUpdateFails = 0;
RTC_DATA_ATTR char rtcUpdateFailedVersion[16] = "";
// The frame's usual check-in interval (the server's X-Retry-Minutes), and how many check-ins in
// a row haven't got through: when the next one fails, it waits that long, doubled for each.
RTC_DATA_ATTR uint32_t rtcRetryMinutes = 0;
RTC_DATA_ATTR uint8_t rtcFailedCheckIns = 0;

Preferences prefs;
String frameId, deviceKey, etag;
String frameCode;          // XXXX-XXXX-XXXX-XXXX, made here, never sent anywhere
bool codePending = false;  // made but not yet registered with the server
// How long to sleep: the server's X-Sleep-Minutes after a check-in, otherwise the usual interval
uint32_t sleepMinutes = SLEEP_MINUTES;
bool checkedIn = false;  // the server answered this wake's check-in
bool wantNext = false;   // woken by KEY2: ask for the next picture
// Plugged in with "stay awake" on: check in again after this long instead of sleeping
// (X-Awake-Seconds, from this wake's check-in; 0 = sleep as usual)
uint32_t awakeSeconds = 0;
// How the frame hangs: "landscape" or "portrait". Chosen in the setup portal (sent to the server
// until it confirms), otherwise whatever the server says (set on the website). Pictures arrive
// already turned for it; this only decides which way up our own messages are drawn.
String orientation = "landscape";
bool orientationPending = false;
// Hung upside down (set on the website, X-Flip): everything is drawn turned 180°, pictures too
bool flip = false;
// Newer firmware the server offered at this check-in (X-Fw-Update etc.), if any
struct { String version, url, sig; size_t size = 0; } offer;

// Hung the other way from how the panel's rows run: messages are turned to read upright
// (rotation 1, matching how the upload page turns pictures: web/dither.js toPanelOrder).
bool turned() { return (orientation == "portrait") != NATIVE_PORTRAIT; }
// The display rotation for our own messages, and for pictures (already in panel order)
int messageRotation() { return (turned() ? 1 : 0) + (flip ? 2 : 0); }
int pictureRotation() { return flip ? 2 : 0; }

// ---- QR code ----------------------------------------------------------------
// ESP-IDF hands the finished code to a callback, so it's copied out here for drawing.

static const int QR_MAX = 57;  // version 10: plenty for a link with the frame ID and code
static bool qrDots[QR_MAX][QR_MAX];
static int qrSize = 0;

static void captureQr(esp_qrcode_handle_t qr) {
  qrSize = esp_qrcode_get_size(qr);
  if (qrSize > QR_MAX) qrSize = 0;
  for (int y = 0; y < qrSize; y++)
    for (int x = 0; x < qrSize; x++) qrDots[y][x] = esp_qrcode_get_module(qr, x, y);
}

// Returns the QR code's size in modules (0 if it couldn't be made); modules are in qrDots.
int makeQr(const char* text) {
  esp_qrcode_config_t cfg = ESP_QRCODE_CONFIG_DEFAULT();
  cfg.display_func = captureQr;
  cfg.max_qrcode_version = 10;
  cfg.qrcode_ecc_level = ESP_QRCODE_ECC_MED;
  qrSize = 0;
  if (esp_qrcode_generate(&cfg, text) != ESP_OK) qrSize = 0;
  return qrSize;
}

// ---------------------------------------------------------------------------

void displayPower(bool on) {
  pinMode(EPD_ENABLE, OUTPUT);
  digitalWrite(EPD_ENABLE, on ? HIGH : LOW);
  if (on) delay(10);
}

#if defined(DOMIFRAME_PANEL_13IN3)

// Drawing for messages (see showMessage): sizes are the 7.3"'s, drawn S times as big here
static const int S = 2;

template <typename Paint>
void drawScreen(Paint paint) {
  displayPower(true);
  epaper.begin();
  epaper.setRotation(messageRotation());  // upright however the frame hangs
  epaper.fillScreen(TFT_WHITE);
  paint();
  epaper.update();
  epaper.sleep();
}

int screenW() { return epaper.width() / S; }
int screenH() { return epaper.height() / S; }
void inkRect(int x, int y, int w, int h, int ink) { epaper.fillRect(x * S, y * S, w * S, h * S, PALETTE[ink]); }
// Text with its baseline at y
// (the fonts are made at this screen's size, so they're drawn 1:1, not doubled)
void inkText(const char* text, int x, int y, const GFXfont* font, int ink) {
  epaper.setFreeFont(font);
  epaper.setTextSize(1);
  epaper.setTextColor(PALETTE[ink]);
  epaper.setTextDatum(L_BASELINE);
  epaper.drawString(text, x * S, y * S);
}
int textWidth(const char* text, const GFXfont* font) {  // in screen units, like everything else
  epaper.setFreeFont(font);
  epaper.setTextSize(1);
  return epaper.textWidth(text) / S;
}

void drawPacked(const uint8_t* buf) {
  displayPower(true);
  epaper.begin();
  epaper.setRotation(pictureRotation());  // the picture's bytes are already in panel order
  for (int y = 0; y < H; y++) {
    const uint8_t* row = buf + (size_t)y * (W / 2);
    for (int x = 0; x < W; x += 2) {
      uint8_t b = row[x >> 1];
      epaper.drawPixel(x, y, PALETTE[(b >> 4) % 6]);
      epaper.drawPixel(x + 1, y, PALETTE[(b & 0x0F) % 6]);
    }
  }
  epaper.update();
  epaper.sleep();
}

#else  // 7.3"

void displayBegin() {
  displayPower(true);
  display.init(115200, true, 2, false);
  display.setRotation(0);
}

// Drawing for messages (see showMessage), at the 7.3"'s own size
static const int S = 1;

template <typename Paint>
void drawScreen(Paint paint) {
  displayBegin();
  display.setFullWindow();
  display.firstPage();
  do {
    display.setRotation(messageRotation());  // upright however the frame hangs
    display.fillScreen(GxEPD_WHITE);
    paint();
  } while (display.nextPage());
  display.hibernate();
}

int screenW() { return display.width() / S; }
int screenH() { return display.height() / S; }
void inkRect(int x, int y, int w, int h, int ink) { display.fillRect(x * S, y * S, w * S, h * S, PALETTE[ink]); }
// Text with its baseline at y
void inkText(const char* text, int x, int y, const GFXfont* font, int ink) {
  display.setFont(font);
  display.setTextSize(S);
  display.setTextColor(PALETTE[ink]);
  display.setCursor(x * S, y * S);
  display.print(text);
}
int textWidth(const char* text, const GFXfont* font) {
  display.setFont(font);
  display.setTextSize(1);
  int16_t x1, y1;
  uint16_t w, h;
  display.getTextBounds(text, 0, 0, &x1, &y1, &w, &h);
  return x1 + w;
}

void drawPacked(const uint8_t* buf) {
  displayBegin();
  display.setRotation(pictureRotation());  // the picture's bytes are already in panel order
  display.setFullWindow();
  display.firstPage();
  do {
    for (int y = 0; y < H; y++) {
      const uint8_t* row = buf + (size_t)y * (W / 2);
      for (int x = 0; x < W; x += 2) {
        uint8_t b = row[x >> 1];
        display.drawPixel(x, y, PALETTE[(b >> 4) % 6]);
        display.drawPixel(x + 1, y, PALETTE[(b & 0x0F) % 6]);
      }
    }
  } while (display.nextPage());
  display.hibernate();
}

#endif

// ---- Messages ----------------------------------------------------------------
// Laid out like the website: the wordmark and its strip of the six inks over a rule, small
// red labels, big black text, a rule and a note at the foot. Sizes are for the 7.3" (S scales
// them on the 13.3"); every screen is at least 480 x 480 of these units, upright either way.

enum Ink { INK_BLACK, INK_WHITE, INK_YELLOW, INK_RED, INK_BLUE, INK_GREEN };  // PALETTE order
static const int MARGIN = 40, HEAD = 88;               // HEAD: the rule under the wordmark

// A 50% checkerboard of one ink: the site's dithered shadows
void inkDither(int x, int y, int w, int h, int ink) {
  for (int yy = y; yy < y + h; yy++)
    for (int xx = x + ((x + yy) & 1); xx < x + w; xx += 2) inkRect(xx, yy, 1, 1, ink);
}

const PfGlyph* wordGlyph(char c) {
  for (const PfGlyph& g : PF_WORD) if (g.c == c) return &g;
  return nullptr;
}

// The wordmark's pixel letters (pixel_font.h), s units a dot, with a red dithered shadow one
// dot down and right, as on the website and in the app; returns their width
int pixelWord(const char* text, int x, int top, int s, int ink) {
  for (int pass = 0; pass < 2; pass++) {  // the shadow, then the letters over it
    int cx = x;
    for (const char* p = text; *p; p++) {
      const PfGlyph* g = wordGlyph(*p);
      if (!g) continue;
      for (int r = 0; r < PF_CAP; r++)
        for (int c = 0; c < g->w; c++)
          if (g->rows[r][c] == '#') {
            if (pass == 0) inkDither(cx + (c + 1) * s, top + (r + 1) * s, s, s, INK_RED);
            else inkRect(cx + c * s, top + r * s, s, s, ink);
          }
      cx += (g->w + PF_SPACING) * s;
    }
    if (pass == 1) return cx - PF_SPACING * s - x;
  }
  return 0;
}

void drawHeader(int w) {
  const int strip[6] = {INK_BLACK, INK_BLUE, INK_GREEN, INK_YELLOW, INK_RED, INK_WHITE};
  int x = MARGIN + pixelWord("DomiFrame", MARGIN, 34, 3, INK_BLACK) + 22;
  inkRect(x - 2, 41, 6 * 16 + 4, 16, INK_BLACK);  // outlined, so the white block shows
  for (int i = 0; i < 6; i++) inkRect(x + i * 16, 43, 16, 12, strip[i]);
  inkRect(MARGIN, HEAD - 3, w - 2 * MARGIN, 3, INK_BLACK);
}

// Cards on the code screen get a dithered shadow this far down and right, as the site's prints
static const int CARD_SHADOW = 6;


// The frame code in one card, read like a line of text: groups of four apart, with a red dash
// between them; on one line at the biggest size that fits maxW, or else on two (the dash at the
// end of the first). Digits blue, letters black, each character drawn to differ from its
// look-alikes (pixel_font.h), PF_CODE_W x PF_CODE_H dots of sc units, CODE_BOLD wider so the
// strokes are heavier than the gaps. web/sim.js codeCard draws the same. Returns its height.
static const int CODE_BOLD = 2;

void drawCodeChar(char ch, int x, int y, int sc) {
  const PfCodeGlyph* g = nullptr;
  for (const PfCodeGlyph& k : PF_CODE) if (k.c == ch) g = &k;
  if (!g) return;
  int ink = isdigit((unsigned char)ch) ? INK_BLUE : INK_BLACK;
  for (int r = 0; r < PF_CODE_H; r++)
    for (int c = 0; c < PF_CODE_W; c++)
      if (g->rows[r][c] == '#') inkRect(x + c * sc, y + r * sc, sc + CODE_BOLD, sc, ink);
}

void showMessage(const char* title, const char* line1, const char* line2 = nullptr) {
  drawScreen([&] {
    drawHeader(screenW());
    inkText(title, MARGIN, HEAD + 70, &PlexTitle, INK_BLACK);
    inkText(line1, MARGIN, HEAD + 130, &PlexBody, INK_BLACK);
    if (line2) inkText(line2, MARGIN, HEAD + 166, &PlexBody, INK_BLACK);
  });
}

// The QR code made by makeQr is drawn QR_MODULE units a module (showCodeScreen)
static const int QR_MODULE = 5;

int readBatteryMv() {
  pinMode(BAT_ADC_ENABLE_PIN, OUTPUT);
  digitalWrite(BAT_ADC_ENABLE_PIN, HIGH);
  delay(10);
  analogReadResolution(12);
  uint32_t sum = 0;
  for (int i = 0; i < 8; i++) sum += analogRead(BAT_ADC_PIN);
  digitalWrite(BAT_ADC_ENABLE_PIN, LOW);
  return (int)((sum / 8.0f) / 4096.0f * BAT_SCALE * 1000.0f);
}

// No battery reading: running on USB power (as the status screen says)
bool onUsb(int mv) { return mv < 1000; }

// ---------------------------------------------------------------------------

void loadSettings() {
  prefs.begin("domiframe", true);
  frameId = prefs.getString("id", "");
  deviceKey = prefs.getString("key", "");
  etag = prefs.getString("etag", "");
  orientation = prefs.getString("orient", "landscape");
  orientationPending = prefs.getBool("orientSet", false);
  flip = prefs.getBool("flip", false);
  frameCode = prefs.getString("code", "");
  codePending = prefs.getBool("codePend", false);
  prefs.end();
}

void saveString(const char* k, const String& v) {
  prefs.begin("domiframe", false);
  prefs.putString(k, v);
  prefs.end();
}

void saveOrientationPending(bool pending) {
  orientationPending = pending;
  prefs.begin("domiframe", false);
  prefs.putBool("orientSet", pending);
  prefs.end();
}

// X-Flip from the server (missing from older ones: left as it is)
void takeFlip(HTTPClient& http) {
  String f = http.header("X-Flip");
  if ((f != "1" && f != "0") || (f == "1") == flip) return;
  flip = f == "1";
  prefs.begin("domiframe", false);
  prefs.putBool("flip", flip);
  prefs.end();
}

void saveCode(const String& code, bool pending) {
  frameCode = code;
  codePending = pending;
  prefs.begin("domiframe", false);
  prefs.putString("code", code);
  prefs.putBool("codePend", pending);
  prefs.end();
}

// ---- Frame code and sealed pictures ---------------------------------------------

static const char CODE_ALPHABET[] = "0123456789ABCDEFGHJKMNPQRSTVWXYZ";  // Crockford base32

// n random characters from CODE_ALPHABET. The hardware RNG is truly random while the radio is
// on, so frame codes are made once Wi-Fi is up.
String randomChars(size_t n) {
  uint8_t bytes[32];
  esp_fill_random(bytes, n);
  String out;
  for (size_t i = 0; i < n; i++) out += CODE_ALPHABET[bytes[i] & 31];
  memset(bytes, 0, sizeof bytes);
  return out;
}

void newFrameCode() {
  String c = randomChars(16);
  saveCode(c.substring(0, 4) + "-" + c.substring(4, 8) + "-" + c.substring(8, 12) + "-" + c.substring(12), true);
  etag = "";  // pictures sealed with the old code are gone
  saveString("etag", etag);
}

// What someone typed as a frame code -> XXXX-XXXX-XXXX-XXXX, or "" if it isn't one. Forgiving
// like the website (web/code.js normalizeCode): any case, spaces or dashes, O/I/L as 0/1/1.
String tidyCode(const char* typed) {
  String c;
  for (const char* p = typed; *p; p++) {
    char ch = toupper((unsigned char)*p);
    if (ch == ' ' || ch == '-') continue;
    if (ch == 'O') ch = '0';
    if (ch == 'I' || ch == 'L') ch = '1';
    if (!strchr(CODE_ALPHABET, ch)) return "";
    c += ch;
  }
  if (c.length() != 16) return "";
  return c.substring(0, 4) + "-" + c.substring(4, 8) + "-" + c.substring(8, 12) + "-" + c.substring(12);
}

void hmacSha256(const uint8_t* key, size_t keyLen, const uint8_t* msg, size_t len, uint8_t out[32]) {
  mbedtls_md_hmac(mbedtls_md_info_from_type(MBEDTLS_MD_SHA256), key, keyLen, msg, len, out);
}

// HKDF-SHA256 (RFC 5869) for one 32-byte block, as web/seal.js frameKeys:
// input = the code without dashes, salt = "domiframe:<frame id>", info = "auth" or "content"
void frameKey(const char* info, uint8_t out[32]) {
  String ikm = frameCode;
  ikm.replace("-", "");
  String salt = "domiframe:" + frameId;
  uint8_t prk[32], msg[16];
  hmacSha256((const uint8_t*)salt.c_str(), salt.length(), (const uint8_t*)ikm.c_str(), ikm.length(), prk);
  size_t n = strlen(info);
  memcpy(msg, info, n);
  msg[n] = 1;
  hmacSha256(prk, sizeof prk, msg, n + 1, out);
  memset(prk, 0, sizeof prk);
}

// SHA-256 (hex) of the access token browsers send: base64url of the "auth" key, unpadded
String accessTokenHash() {
  uint8_t auth[32], b64[48], digest[32];
  size_t len = 0;
  frameKey("auth", auth);
  mbedtls_base64_encode(b64, sizeof b64, &len, auth, sizeof auth);
  while (len && b64[len - 1] == '=') len--;
  for (size_t i = 0; i < len; i++) {
    if (b64[i] == '+') b64[i] = '-';
    if (b64[i] == '/') b64[i] = '_';
  }
  mbedtls_md(mbedtls_md_info_from_type(MBEDTLS_MD_SHA256), b64, len, digest);
  memset(auth, 0, sizeof auth);
  char hex[65];
  for (int i = 0; i < 32; i++) sprintf(hex + i * 2, "%02x", digest[i]);
  return String(hex);
}

// Opens a sealed picture into out (IMAGE_BYTES). False if it wasn't sealed with our code.
// AES-GCM decryption, written out: AES-CTR for the data and GHASH for the tag. The ESP32-S3's
// built-in GCM gave wrong tags for a whole 192 KB picture (it can't be done in one call from
// internal RAM, and split up, the hardware GHASH goes wrong), while its plain AES block
// cipher is reliable. Only the AES block is the hardware's here; GHASH is in software.
struct Gcm {
  mbedtls_aes_context aes;
  uint8_t h[16];      // the hash key: AES(0)
  uint8_t ghash[16];  // the running hash
};

// x = x * h in GF(2^128), as GCM defines it (bit-reflected, R = 0xE1 || 0^120)
static void gfMul(uint8_t x[16], const uint8_t h[16]) {
  uint8_t z[16] = {0}, v[16];
  memcpy(v, h, 16);
  for (int i = 0; i < 128; i++) {
    if (x[i / 8] & (0x80 >> (i % 8)))
      for (int k = 0; k < 16; k++) z[k] ^= v[k];
    bool lsb = v[15] & 1;
    for (int k = 15; k > 0; k--) v[k] = (v[k] >> 1) | (v[k - 1] << 7);
    v[0] >>= 1;
    if (lsb) v[0] ^= 0xE1;
  }
  memcpy(x, z, 16);
}

static void ghashBlock(Gcm& g, const uint8_t* block, size_t n) {
  for (size_t i = 0; i < n; i++) g.ghash[i] ^= block[i];
  gfMul(g.ghash, g.h);
}
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
void loop() {}

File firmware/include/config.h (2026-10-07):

#pragma once

// ---- Server ---------------------------------------------------------------
#define SERVER_BASE "https://domiframe.art"
#define FW_VERSION "0.9.8"  // tools/release.py publishes it; raise it for every release

// Which build this is, so updates over Wi-Fi only ever bring the same build (platformio.ini envs)
#if defined(DOMIFRAME_PANEL_13IN3)
#define FW_ENV "ee02-13in3"
#else
#define FW_ENV "ee04"
#endif

// Updates over Wi-Fi need this much battery (millivolts): a download that dies halfway is
// harmless, but there's no point starting one on a flat battery. Readings under 1 V mean no
// battery is connected (running on USB), and don't count.
#define MIN_UPDATE_MV 3550

// Check the server's HTTPS certificate against Mozilla's root CAs (data/cert). 0 skips the
// check, for debugging only: anyone on the frame's network could then read its device key.
#define VERIFY_TLS 1

// How often the frame wakes to check for a new picture when the server doesn't say
// (offline, or an old server). Normally the server sends X-Sleep-Minutes, set per frame on
// the upload/admin pages, clamped to this range.
#define SLEEP_MINUTES 60
#define MIN_SLEEP_MINUTES 5
#define MAX_SLEEP_MINUTES (7 * 24 * 60)
// Plugged in with "stay awake" on, the server sends X-Awake-Seconds instead (netlify/lib/schedule.mjs
// AWAKE_SECONDS): the frame stays up and checks in that often. Taken only in this range.
#define MIN_AWAKE_SECONDS 15
#define MAX_AWAKE_SECONDS 3600
// After check-ins that don't get through (no Wi-Fi, or the server doesn't answer), the frame
// waits twice as long after each one in a row, up to this, so a frame whose network is down
// doesn't spend its battery on the radio every hour.
#define MAX_OFFLINE_SLEEP_MINUTES (12 * 60)

// An empty battery (millivolts, read before Wi-Fi is on): the frame stops checking in, keeping its
// picture up, and looks again every FLAT_CHECK_MINUTES (without Wi-Fi) until the battery is back
// over RESUME_MV, from charging. The server's own low-battery slowdown starts well
// before this (LOW_BATTERY_MV in netlify/lib/schedule.mjs).
#define FLAT_MV 3350
#define RESUME_MV 3700
#define FLAT_CHECK_MINUTES (6 * 60)

// ---- XIAO ePaper Display Board EE04 (XIAO ESP32-S3 Plus) --------------------
// From Seeed_GFX User_Setups/EPaper_Board_Pins_Setups.h (USE_XIAO_EPAPER_DISPLAY_BOARD_EE04)
#define EPD_CS 44      // D7
#define EPD_DC 10      // D16
#define EPD_RST 38     // D11
#define EPD_BUSY 4     // D3
#define EPD_ENABLE 43  // D6, drive HIGH to power the panel
// SPI: SCK = D8, MOSI = D10 (XIAO default SPI pins)

// Buttons (from Seeed EE04 wiki; active LOW)
#define BTN_REFRESH 2  // KEY1: wake and check for a new picture now
#define BTN_SETUP 5    // KEY3: hold while powering on / pressing reset to reopen Wi-Fi setup
#define BTN_NEXT 3     // KEY2: wake and put up the next picture; hold while pressing reset for status

// Battery sense (from Seeed EE04 wiki)
#define BAT_ADC_PIN 1        // A0
#define BAT_ADC_ENABLE_PIN 6 // A5, HIGH while measuring
#define BAT_SCALE 7.16f      // volts = raw / 4096 * BAT_SCALE

// Wi-Fi setup (portal.cpp): the frame's own network, and how long the setup page stays open
// after it was last used
#define SETUP_AP_NAME "DomiFrame-Setup"
#define SETUP_PORTAL_TIMEOUT_S 600

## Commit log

2026-09-30 Initial DomiFrame scaffold: Netlify server, upload page, EE04 firmware
    - Netlify Functions + Blobs API: admin frame creation, device image fetch with ETag, friend uploads
    - Mobile upload page with in-browser Spectra 6 dithering and preview
    - PlatformIO firmware for XIAO ePaper EE04 + 7.3" Spectra 6 (Wi-Fi portal, deep sleep, button wake)
    - Tests for dithering and the full API flow
    Claude-Session: https://claude.ai/code/session_01E7VETTgeVX22xpjKaESX4S
2026-09-30 Image pipeline: color controls, more dithering styles, faster dithering
    - Adjustments: contrast, shadows (gamma), warmth, tint, sharpen, dither strength
    - Dithering styles: Floyd–Steinberg, Atkinson, Jarvis–Judice–Ninke, Stucki,
    Burkes, Sierra, Sierra Lite, Bayer (ordered), none
    - Color boost 0 dithers with only the black and white inks
    - 2-2.5x faster inner loops (bit-identical output), plus a worker so the
    upload page can dither off the main thread
2026-09-30 Server: picture queue, folders, schedules and frame orientation
    - Each frame keeps up to 200 pictures; new ones go up at the next check-in,
    bulk imports join the rotation, "show next" puts one up on demand
    - Rotation every 1h-1 week (or only on new pictures), in order or shuffled,
    optionally limited to one folder
    - The server tells the frame when to wake (X-Sleep-Minutes): check-in
    interval, rotation timing, quiet hours, fewer check-ins on low battery
    - Frame orientation setting (X-Orientation), settable from the frame itself
    via X-Set-Orientation
    - Originals and editor settings kept so pictures can be edited again
    - Management API: folders, bulk move/delete, replace, settings
    - Admi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
2026-09-30 Firmware: server-controlled sleep and frame orientation
    - Sleep for the server's X-Sleep-Minutes (clamped 5 min-1 week), falling
    back to SLEEP_MINUTES
    - Setup portal asks how the frame hangs; sent via X-Set-Orientation until
    the server confirms, and kept in sync with X-Orientation
    - Status messages drawn upright on a portrait-hung frame
    - KEY1 wake uses ESP_EXT1_WAKEUP_ANY_LOW (ALL_LOW is deprecated on the S3)
    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
2026-09-30 Upload page: photo editor, collection and new gallery look
    Editor
    - Choose several photos or a whole folder; click through them in a filmstrip
    - Per-photo cropping (zoom, drag, rotate); looks apply to all photos or just
    one, setting by setting
    - Presets, light/color/detail tabs, dithering style, optional name label
    - Auto fit: fills the frame with photos of its shape, fits others over a
    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
2026-09-30 Add admin page
    Sign in with ADMIN_TOKEN to create frames (upload link, QR code and device
    key shown once), see battery and check-ins, open a frame's collection, turn
    its orientation, replace leaked keys, or delete it.
2026-09-30 Local development: run everything without hardware
    - npm run local: site + API with a local Blobs store in .local/, a demo frame,
    and a dev-only clock (/__dev/clock) for testing schedules
    - Virtual frame (scripts/sim.html): checks in like the firmware, follows the
    server's sleep times (real time or sped up), skips ahead hours/days/weeks,
    and can set how the frame hangs
    - .claude/launch.json for the app's preview pane
2026-09-30 Support the 13.3" screen: screen size per frame
    - PANELS in web/dither.js: 7.3" (800x480, landscape rows) and 13.3"
    (1600x1200 pictures, 1200x1600 portrait rows); pictures are packed in the
    panel's own row order
    - Frame setting `panel`, set when creating a frame or reported by the
    firmware on every check-in (X-Panel)
    - Uploads must match the frame's screen size; pictures made for another
    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
2026-09-30 Firmware: 13.3" build for the EE02 board
    - New PlatformIO env ee02-13in3 using Seeed_GFX (BOARD_SCREEN_COMBO=510),
    pinned to a known commit; ee04 (7.3", GxEPD2) stays the default
    - Shared Wi-Fi, check-in, sleep and setup code; sends X-Panel
    - Status messages upright whenever the frame hangs across its panel's rows
    - CI builds and publishes both firmwares. FW 0.4.0
2026-09-30 13.3" screen in the upload page, admin page and virtual frame
    - Upload page makes pictures at the frame's screen size, shows it next to
    the orientation switch, and offers to rebuild pictures made for another
    size; half-size previews for the big screen
    - Admin page: choose the screen when creating a frame
    - Virtual frame: screen size choice (sent as X-Panel), 1200x1600 panels
2026-09-30 Use in-page dialogs instead of browser confirm/prompt/alert
    Browsers let people block a page's dialogs; after that confirm() silently
    returns false, so "Remove all" (and removing pictures, folder actions, key
    replacement, deleting frames) did nothing. web/dialog.js provides a styled
    <dialog> for confirmations, text input and type-to-confirm.
2026-09-30 Firmware: verify TLS with Mozilla roots, faster Wi-Fi reconnect
    - Check the server's certificate against Mozilla's root CAs, embedded as
    firmware/data/cert/x509_crt_bundle.bin (VERIFY_TLS in config.h), instead
    of skipping verification. tools/make_ca_bundle.py rebuilds the bundle and
    --check <host> tests a server the way the ESP32 does (it only looks up
    the issuer of the last certificate sent); extra_roots.pem adds any root
    a host needs beyond Mozilla's list.
    - Remember the access point and channel in RTC memory and reconnect without
    scanning, falling back to a normal connect. Never rewrites the saved network.
    - Server is domiframe.art. FW 0.5.0.
    - CI: weekly job checks the frames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
    [config.h, main.cpp, make_ca_bundle.py]
2026-09-30 Site: new look, home page with frame codes, safer and lighter backend
    Backend
    - Picture queue changes are conditional writes (onlyIfMatch) with retries,
    plus a per-frame lock in-process, so a check-in during an upload can't
    lose a picture. Test races 8 uploads against 4 check-ins.
    - Small JPEG thumbnails for the picture grid (/pictures/:pic/thumb, falling
    back to the PNG preview), ~10x less to download; picture files served
    immutable since ids never change.
    - Upload keys are typeable frame codes (XXXX-XXXX-XXXX-XXXX, 80 bits);
    older long keys keep working.
    - Faster palette check; netlify.toml skips deploys for pushes that don't
    touch the site.
    Site
    - Restyled after the e-paper p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
2026-09-30 End-to-end encrypted pictures, frame-made codes, virtual frame on the site
    - Frames make their own frame code and show it on screen; the server only
    gets a hash of a token derived from it. Browsers seal pictures, previews,
    originals, edits, sender and folder names with an AES-256-GCM key from the
    code (web/seal.js), and the firmware opens them with the same key.
    - The admin can no longer see or change anyone's pictures, and never gets a
    frame code. New POST /api/frames/:id/code for the frame to register one.
    - Security headers: strict CSP, HSTS, framing and permissions policies;
    third-party QR script removed; admin token kept per tab only.
    - Setup portal Wi-Fi has a random password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
    [config.h, main.cpp]
2026-09-30 QR code on the frame's code screen; real photo as the home page sample
    - The frame and the virtual frame show a QR code of the frame's page link
    with the code after the #, so a phone opens it ready to use. Firmware uses
    ESP-IDF's QR encoder; the virtual frame uses a vendored copy of
    qrcode-generator (no third-party scripts, per the CSP).
    - The home page's example picture is now a photo, dithered in the browser.
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2026-10-01 Light/dark toggle in every page's header
    Follows the system setting until picked; the choice is kept on the device and
    applied before the page draws.
2026-10-01 Frame page: invite by QR code, pictures for a day, captions and dates, undo
    - Invite someone: the frame's link as a QR code, with copy and share
    - Show a picture only on a day (every year or once), in the frame's time zone
    - Text on pictures: caption, date taken (from EXIF, editable), signature, any corner,
    drawn as a gallery-style label in the frame's inks
    - Removed pictures go to Recently removed for 30 days, with Undo right away
2026-10-01 Frames keep the screen size chosen when they were created
    The virtual frame reported its default 7.3" screen on every check-in,
    overwriting the 13.3" chosen on the admin page. Now check-in replies say
    the frame's screen size (X-Panel, like X-Orientation), the virtual frame
    only reports a size when one is picked on it and otherwise takes the
    server's, and remembers it per frame. The admin page's virtual frame link
    includes the size.
2026-10-01 Spacing pass: Add pictures above the collection, tighter forms, even buttons
    - Frame page: the collection moves to its own card below Add pictures, so
    sending a picture no longer means scrolling past every picture first
    - Empty status lines take no space at the bottom of cards
    - The "frame shows" folder picker stops at 420px on wide screens
    - Admin: wordmark before the ink strip like the other pages, even gaps in
    the forms, room above the frame actions; fits one line on phones
    - Home: the two hero buttons are the same height
    - Virtual frame: header fits on phones, button rows line up
    Claude-Session: https://claude.ai/code/session_0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
2026-10-01 Editor preview without dithering; tell people to press the frame's button
    The editor shows the adjusted photo and its label, not the ink dots: a screen can't show them
    the way e-paper does. The worker still dithers alongside (ditherWithPreview), and the uploaded
    preview and thumbnail come from the dithered picture, not the canvas. The Detail tab and the
    preview note explain it. After sending or saving, the message says to press the button on the
    frame to see it now.
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2026-10-01 Show the frame code with KEY1 + reset without Wi-Fi
    [main.cpp]
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2026-10-02 Firmware 0.8.0: back off when offline, rest on an empty battery; keep old frame codes
    Firmware:
    - A picture that downloads whole but won't open keeps its ETag, so it
    isn't downloaded again at every wake
    - Failed check-ins retry at the usual interval (new X-Retry-Minutes),
    doubling for each failure in a row, up to 12 hours
    - Nearly empty battery: stop checking in, leave the picture up, and read
    the battery every 6 hours without Wi-Fi until it's charged
    - Read the battery before Wi-Fi, so the radio doesn't pull it down
    Upload page: when a frame's code stops working, keep the old code (it
    brings the pictures back within 30 days) and ask for the new one there.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
    [config.h, main.cpp]
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2026-10-04 Firmware 0.9.1: the code screen as a ticket
    The frame ID first, then the code in one card that reads like a line of text (red dashes
    between the groups, two lines when it doesn't fit on one), and the QR code under SCAN TO OPEN.
    The same on the virtual frame.
    [config.h, main.cpp]
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2026-10-04 Firmware: open pictures in chunks through internal RAM
    On the first real frame every picture failed to open: the 192 KB sealed picture is in PSRAM,
    and the ESP32-S3's AES accelerator doesn't decrypt large PSRAM buffers reliably. Decrypt in
    4 KB chunks copied to internal RAM, check the tag ourselves, and log a fingerprint of the
    code when one still won't open, to tell a wrong code from a decryption problem.
    [main.cpp]
2026-10-04 Firmware: open pictures with AES-CTR and a software GHASH
    The frame's and the app's codes and keys match (same token hash), yet every picture failed its
    tag: the ESP32-S3's built-in GCM can't do a 192 KB picture in one call from internal RAM, and
    split into pieces its hash goes wrong. Decrypt with the AES block cipher (reliable, it's what
    HTTPS uses) in counter mode, and compute GHASH in software. A self-test at start opens a sample
    sealed by web/seal.js. Checked offline against a full-size picture sealed by the website.
    [main.cpp]
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2026-10-04 Enclosure: printable case for the EE04 board and 7.3" panel
    [back.stl, domiframe_case.scad, door.stl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]
2026-10-04 Firmware: friendlier Wi-Fi setup, opened by itself when the frame has moved
    Replace WiFiManager with a setup page the frame serves itself (portal.cpp):
    one page with the networks in range, a password and how the frame hangs,
    styled like the site. The frame ID, device key and frame code sit under
    Frame details once set. A wrong password keeps the page open and says so;
    success says "All set". WiFiManager's unsigned firmware upload is gone.
    The setup screen shows a QR code that joins the frame's own network.
    When someone switches the frame on, resets it or presses KEY1 and it
    can't reach its Wi-Fi (moved, or given away), setup opens by itself.
    Timer wakes still keep the picture up and back of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
    [config.h, main.cpp]
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2026-10-04 Guides: the new Wi-Fi setup everywhere, moving a frame, and giving one
    Support page: KEY1 and reset open Wi-Fi setup when the frame can't reach
    its Wi-Fi; a new home is just switching the frame on there; getting old
    pictures back goes through Frame details; and a new section on giving a
    frame as a present (preload it, switch it off, what a new code costs).
    The upload and admin pages no longer say "setup portal".
2026-10-05 update enclosure
    [back.stl, domiframe_case.scad, door.stl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]
2026-10-05 Site: App Store link and short links for the guides
    /app (placeholder App Store URL until the app is live), /setup, /help, /wifi,
    /gift, /buttons and /issues, as 302s in netlify.toml (the local server follows
    them too). The home page gets an iPhone app section and button, every footer
    links the app, support explains it, and the invite dialog says links open in it.
2026-10-05 Enclosure: label the buttons on the back plate
    RESET, 1 CHECK, 2 NEXT and 3 SETUP are engraved into the back plate, each
    under its button with a mark pointing up at it (the top wall beside the
    door is too thin for text). Positions are the `buttons` parameter, still
    guesses: measure before printing, or set button_labels = false.
    [back.stl, domiframe_case.scad]
2026-10-05 KEY2: the next picture, and a status screen; plainer help for a new owner
    Press KEY2 and the frame wakes and asks for the next picture (X-Next),
    which then stays up a whole turn. Hold KEY2 while pressing reset for a
    status screen: battery, Wi-Fi and signal, whether the server answers (an
    X-Status check-in that leaves the picture as it is), the last check-in in
    the frame's time zone (X-Local-Time, kept in flash) and the firmware.
    The virtual frame has both.
    "Frame not registered" now tells someone given a frame to ask whoever set
    it up, and the setup page's "All set" says how to get the frame code
    (hold KEY1 and press reset) to send it pictures. Support and README
    describe KEY2 and where the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
    [config.h, main.cpp]
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2026-10-05 Upside down: a frame can hang turned over
    A new `flip` setting, sent to the frame as X-Flip. Firmware 0.9.7 turns everything it draws
    180°, so pictures already on the frame still show the right way up; the picture's ETag
    changes with it, so the frame draws it again. A switch on the frame page, a button on the
    admin page, and the virtual frame moves its chin to the top.
    [config.h, main.cpp]
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2026-10-06 Enclosure: press-fit button caps, a switch slot, wall and table mounts
    The slot and door in the top wall are gone. The top wall now has an
    opening for the USB-C plug and a hole over each button, and a printed
    cap presses onto each switch plunger. The slide switch gets its own
    slot and a cap with a wider tab. A fit-test print sizes the sockets.
    A sawtooth bracket screws into the solid frame down either long side
    for portrait, or onto a rail across the top for landscape. Two
    slip-on feet stand the frame on a table either way round. The back
    plate screw holes in the frame are wider and deeper.
    [back.stl, buttons.stl, domiframe_case.scad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]
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2026-10-23 Enclosure: button and switch caps go deeper, with looser sockets
    Plungers and the switch knob are 2.0 mm long, and each cap goes as far onto them as leaves
    the switch body clear. Sockets are drawn larger (2.5 mm, 1.75 mm square), since printed holes
    come out small; the fit test steps around the new sizes.
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
